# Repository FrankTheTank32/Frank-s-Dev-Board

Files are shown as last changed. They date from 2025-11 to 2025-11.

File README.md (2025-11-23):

This respository includes the bill of materials (BOM), GRBR and DRL files for PCB manufacturing and specifications, as well as the entire project folder itself for importing into KiCAD.

The DevBoard is comprised of an RP2040 microcontroller, lights, 43 pins total, an IMU, and a nice silkscreen design. It resembles the shape of an "F" after the name frame, and has the meming frog, as that also starts with an "F". This development board is extremely useful if you're looking to have a highly functional (and highly energetic) microcontroller electronics maker experience.

PCB design in 2D

Finished PCB

PCB design in 3D

PCBfinished

ENJOY!!!

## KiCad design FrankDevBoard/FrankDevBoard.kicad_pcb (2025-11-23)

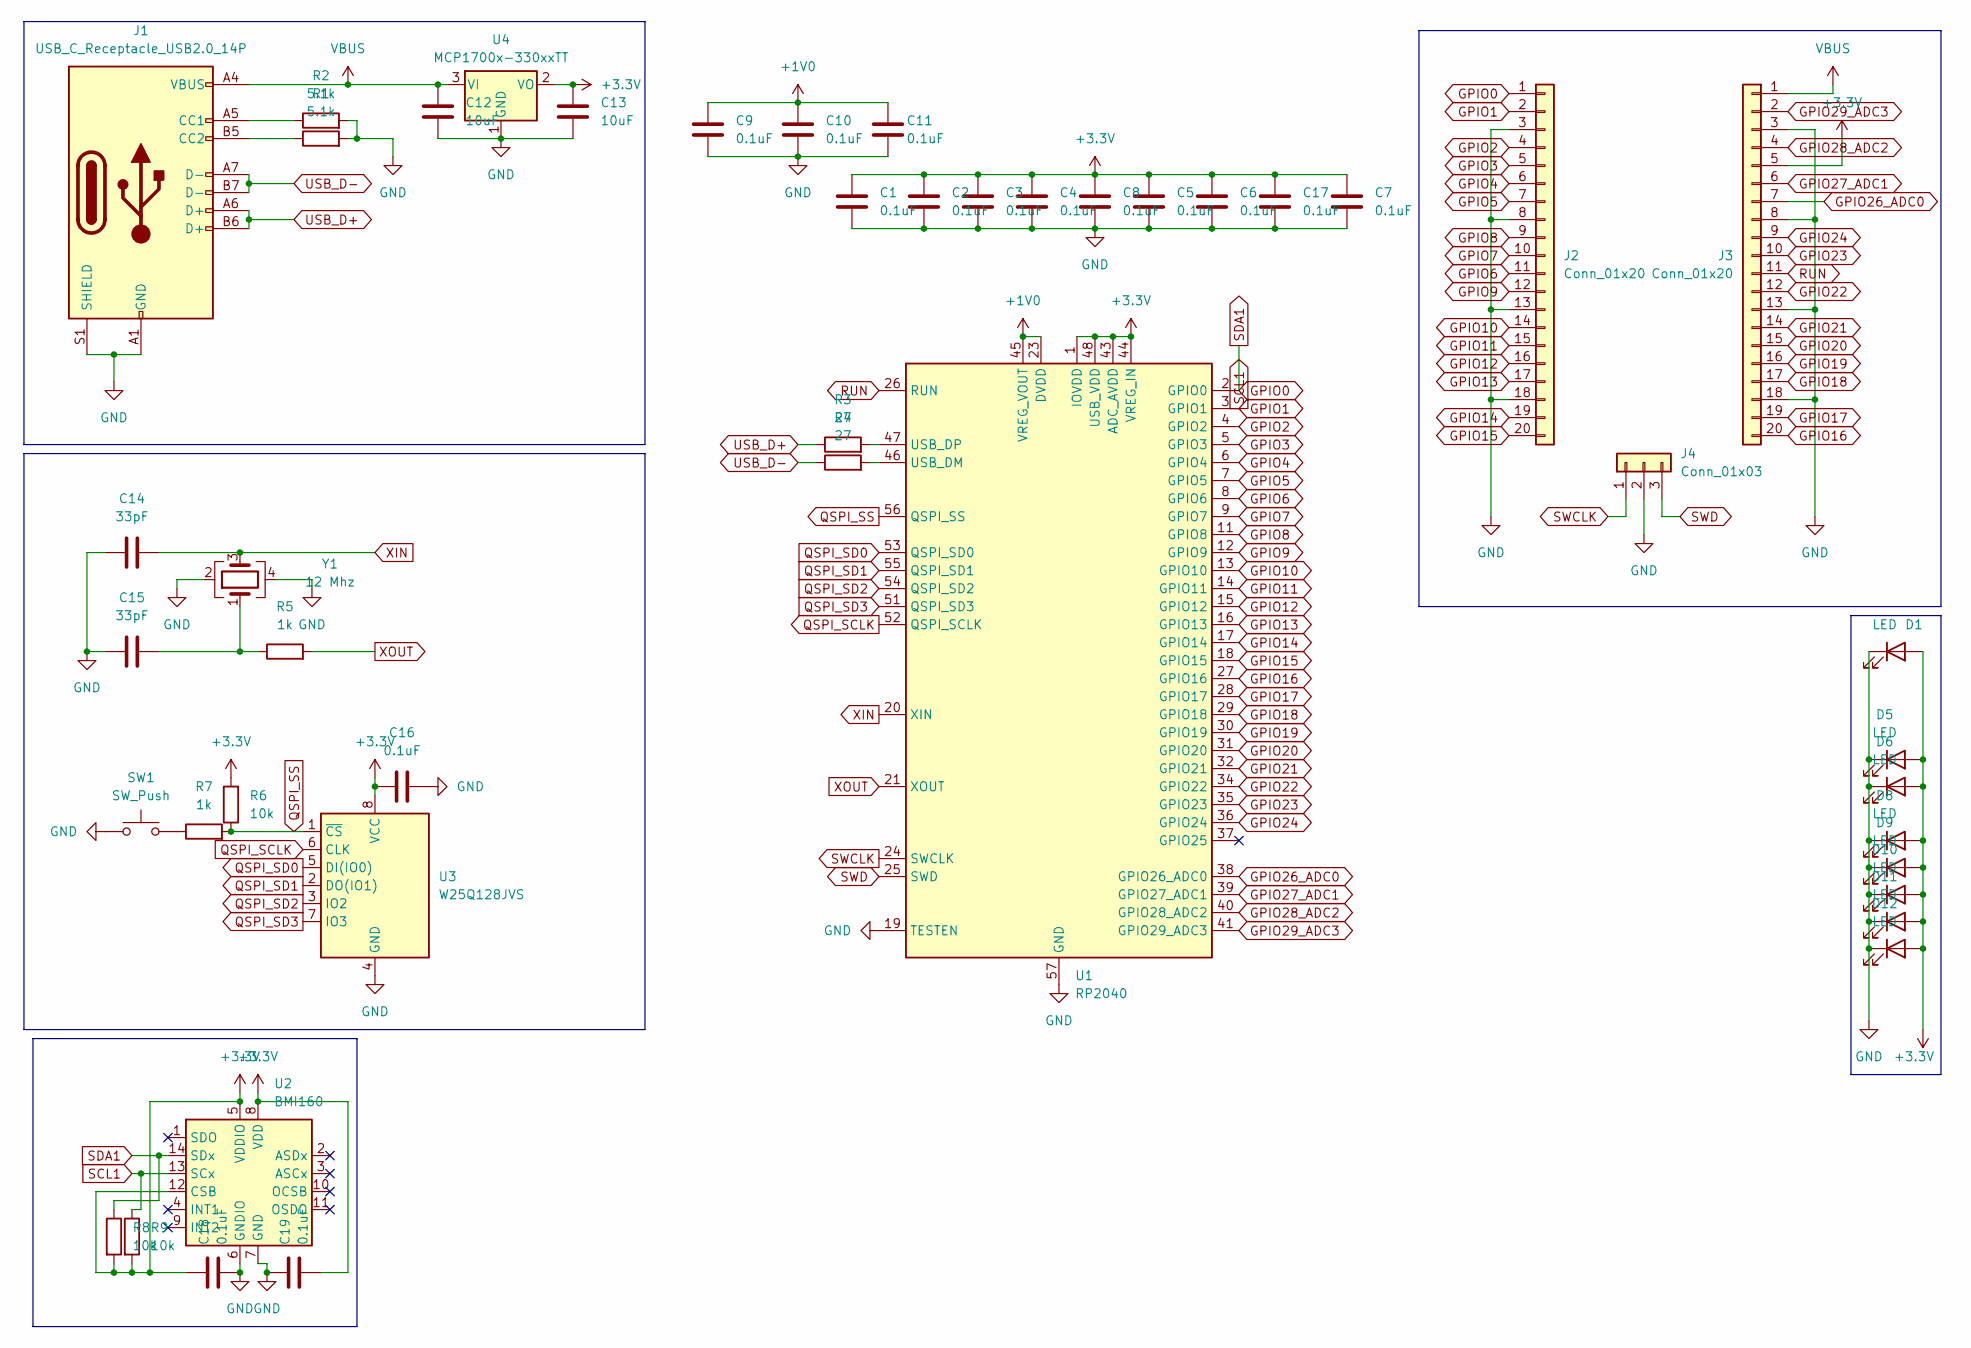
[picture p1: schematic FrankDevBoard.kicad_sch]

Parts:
C1, C2, C3, C4, C5, C6, C7, C8, C9, C10, C11, C16, C17, C18, C19: 0.1uF; C_0402_1005Metric
C12, C13: 10uF; C_0603_1608Metric
C14, C15: 33pF; C_0402_1005Metric
D1, D5, D6, D8, D9, D10, D11, D12: LED; LED_1210_3225Metric
J1: USB_C_Receptacle_USB2.0_14P; USB_C_Receptacle_HRO_TYPE-C-31-M-12
J2, J3: Conn_01x20; PinHeader_1x20_P2.54mm_Vertical
J4: Conn_01x03; PinHeader_1x03_P2.54mm_Vertical
R1, R2: 5.1k; R_0402_1005Metric
R3, R4: 27; R_0402_1005Metric
R5, R7: 1k; R_0402_1005Metric
R6, R8, R9: 10k; R_0402_1005Metric
SW1: SW_Push; SW_Push_SPST_NO_Alps_SKRK
U1: RP2040; QFN-56-1EP_7x7mm_P0.4mm_EP3.2x3.2mm
U2: BMI160; Bosch_LGA-14_3x2.5mm_P0.5mm
U3: W25Q128JVS; SON-8-1EP_3x2mm_P0.5mm_EP1.4x1.6mm
U4: MCP1700x-330xxTT; SOT-23
Y1: 12 Mhz; Crystal_SMD_3225-4Pin_3.2x2.5mm

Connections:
+1V0: C9.1, C10.1, C11.1, U1.23 (DVDD), U1.45 (VREG_VOUT), U1.50 (DVDD)
+3.3V: C1.1, C2.1, C3.1, C4.1, C5.1, C6.1, C7.1, C8.1, C13.1, C16.1, C17.1, C18.1, C19.2, D1.2 (A), D5.2 (A), D6.2 (A), D8.2 (A), D9.2 (A), D10.2 (A), D11.2 (A), D12.2 (A), J3.5, R6.2, R8.2, R9.2, U1.1 (IOVDD), U1.10 (IOVDD), U1.22 (IOVDD), U1.33 (IOVDD), U1.42 (IOVDD), U1.43 (ADC_AVDD), U1.44 (VREG_IN), U1.48 (USB_VDD), U1.49 (IOVDD), U2.5 (VDDIO), U2.8 (VDD), U2.12 (CSB), U3.8 (VCC), U4.2 (VO)
GND: C1.2, C2.2, C3.2, C4.2, C5.2, C6.2, C7.2, C8.2, C9.2, C10.2, C11.2, C12.2, C13.2, C14.1, C15.1, C16.2, C17.2, C18.2, C19.1, D1.1 (K), D5.1 (K), D6.1 (K), D8.1 (K), D9.1 (K), D10.1 (K), D11.1 (K), D12.1 (K), J1.A1 (GND), J1.A12 (GND), J1.B1 (GND), J1.B12 (GND), J1.S1 (SHIELD), J2.3, J2.8, J2.13, J2.18, J3.3, J3.8, J3.13, J3.18, J4.2, R1.2, R2.2, SW1.1, U1.19 (TESTEN), U1.57 (GND), U2.6 (GNDIO), U2.7 (GND), U3.4 (GND), U4.1 (GND), Y1.2, Y1.4
GPIO0: J2.1, R8.1, U1.2 (GPIO0), U2.14 (SDx)
GPIO1: J2.2, R9.1, U1.3 (GPIO1), U2.13 (SCx)
GPIO2: J2.4, U1.4 (GPIO2)
GPIO3: J2.5, U1.5 (GPIO3)
GPIO4: J2.6, U1.6 (GPIO4)
GPIO5: J2.7, U1.7 (GPIO5)
GPIO6: J2.11, U1.8 (GPIO6)
GPIO7: J2.10, U1.9 (GPIO7)
GPIO8: J2.9, U1.11 (GPIO8)
GPIO9: J2.12, U1.12 (GPIO9)
GPIO10: J2.14, U1.13 (GPIO10)
GPIO11: J2.15, U1.14 (GPIO11)
GPIO12: J2.16, U1.15 (GPIO12)
GPIO13: J2.17, U1.16 (GPIO13)
GPIO14: J2.19, U1.17 (GPIO14)
GPIO15: J2.20, U1.18 (GPIO15)
GPIO16: J3.20, U1.27 (GPIO16)
GPIO17: J3.19, U1.28 (GPIO17)
GPIO18: J3.17, U1.29 (GPIO18)
GPIO19: J3.16, U1.30 (GPIO19)
GPIO20: J3.15, U1.31 (GPIO20)
GPIO21: J3.14, U1.32 (GPIO21)
GPIO22: J3.12, U1.34 (GPIO22)
GPIO23: J3.10, U1.35 (GPIO23)
GPIO24: J3.9, U1.36 (GPIO24)
GPIO26_ADC0: J3.7, U1.38 (GPIO26_ADC0)
GPIO27_ADC1: J3.6, U1.39 (GPIO27_ADC1)
GPIO28_ADC2: J3.4, U1.40 (GPIO28_ADC2)
GPIO29_ADC3: J3.2, U1.41 (GPIO29_ADC3)
unnamed: C15.2, R5.1, Y1.1
unnamed: J1.A5 (CC1), R2.1
unnamed: J1.B5 (CC2), R1.1
unnamed: R7.1, SW1.2
unnamed: R4.2, U1.46 (USB_DM)
unnamed: R3.2, U1.47 (USB_DP)
QSPI_SCLK: U1.52 (QSPI_SCLK), U3.6 (CLK)
QSPI_SD0: U1.53 (QSPI_SD0), U3.5 (DI(IO0))
QSPI_SD1: U1.55 (QSPI_SD1), U3.2 (DO(IO1))
QSPI_SD2: U1.54 (QSPI_SD2), U3.3 (IO2)
QSPI_SD3: U1.51 (QSPI_SD3), U3.7 (IO3)
QSPI_SS: R6.1, R7.2, U1.56 (QSPI_SS), U3.1 (~CS)
RUN: J3.11, U1.26 (RUN)
SWCLK: J4.1, U1.24 (SWCLK)
SWD: J4.3, U1.25 (SWD)
USB_D+: J1.A6 (D+), J1.B6 (D+), R3.1
USB_D-: J1.A7 (D-), J1.B7 (D-), R4.1
VBUS: C12.1, J1.A4 (VBUS), J1.A9 (VBUS), J1.B4 (VBUS), J1.B9 (VBUS), J3.1, U4.3 (VI)
XIN: C14.2, U1.20 (XIN), Y1.3
XOUT: R5.2, U1.21 (XOUT)

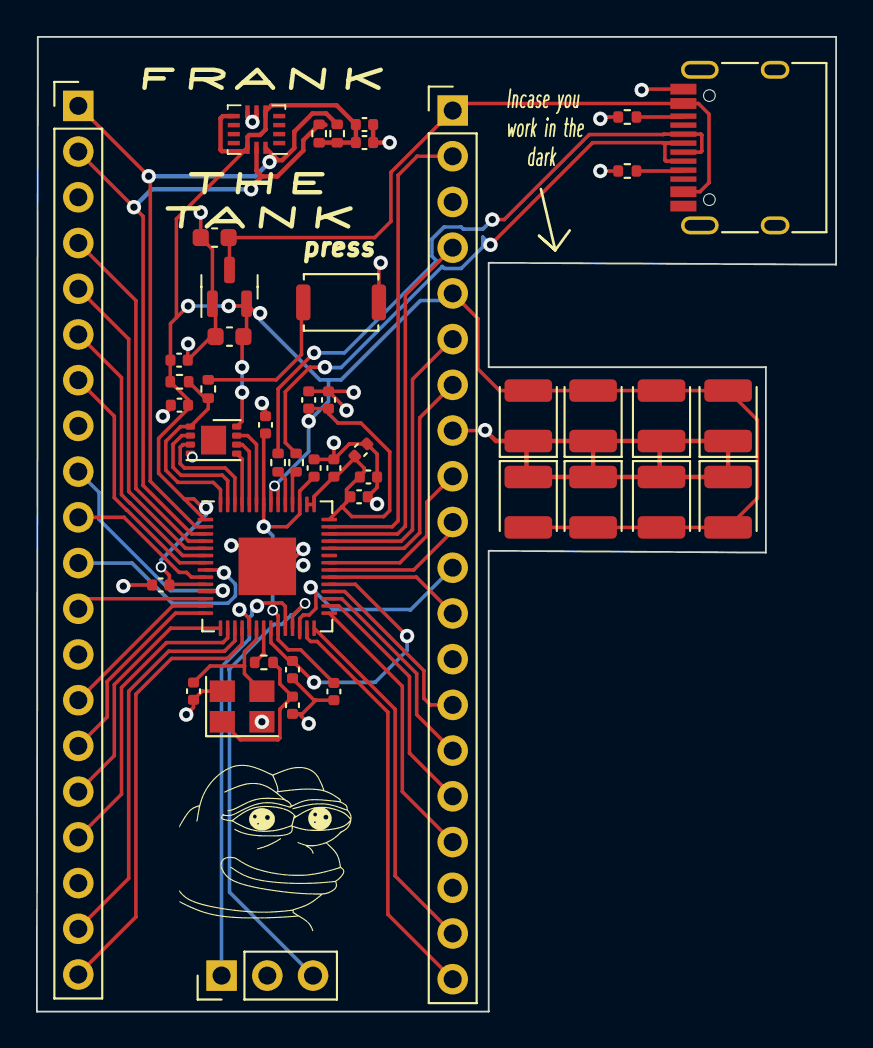
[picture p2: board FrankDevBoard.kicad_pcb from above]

Board: 2 copper layers, 44.4 x 54.1 mm, 46 parts (0 on the bottom side), 52 nets.
